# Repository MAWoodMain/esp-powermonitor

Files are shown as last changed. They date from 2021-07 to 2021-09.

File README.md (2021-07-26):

# ESP32-S2 Based Power Meter
This projects sets out to create a standalone power meter with 4 current channels and a voltage channel, this unit should be able to take measurement and publish calibrated values over MQTT to homeassistant and other applications.
This design will focus on having a smaller package and power consumption then similar RPI based solutions like my earlier designs. This design will also integrate a battery backup system to data can be captured during supply drop outs.

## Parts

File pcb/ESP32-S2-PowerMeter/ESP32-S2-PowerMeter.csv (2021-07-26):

Comment | Designator | Footprint | LCSC Part #
1uF Unpolarized capacitor, small symbol | C1,C2,C13 | C_0603_1608Metric | C15849
100nF Unpolarized capacitor, small symbol | C3,C4,C7,C8,C9,C10,C11,C12 | C_0402_1005Metric | C1525
10uF Polarized capacitor, small symbol | C5,C6 | CP_EIA-3216-18_Kemet-A | C7171
FM-B2020RGBA-HG RGB LED, anode/red/green/blue | D1 | FM-B2020RGBA-HG | C108793
ESD9B3.3ST5G ESD protection diode, 3.3Vrwm, SOD-923 | D2,D3,D4,D5 | SMD-DFN1006 | C316039
600R@100MHz Ferrite bead, small symbol | FB1 | L_0402_1005Metric | C96687
MountingHole Mounting Hole without connection | H1 | MountingHole_3.2mm_M3
USB_C_Receptacle_USB2.0 USB 2.0-only Type-C Receptacle connector | J1 | TYPEC-304S-ACP16 | C720630
Battery Generic connector, single row, 01x02, script generated (kicad-library-utils/schlib/autogen/connector/) | J2 | JST_PH_S2B-PH-SM4-TB_1x02-1MP_P2.00mm_Horizontal | C225233
AudioJack3 Audio Jack, 3 Poles (Stereo / TRS) | J3,J4,J5,J6 | PJ-327F | C128989
AC In DC Barrel Jack with an internal switch | J7 | DC-005-5A-2.0-SMT | C319134
Power Path Bypass Solder Jumper, 2-pole, open | JP1 | SolderJumper-2_P1.3mm_Open_RoundedPad1.0x1.5mm
150R Resistor, small symbol | R1 | R_0402_1005Metric | C25082
120R Resistor, small symbol | R2,R3,R4 | R_0402_1005Metric | C25079
5K1 Resistor | R5,R6 | R_0402_1005Metric | C25905
10K Resistor | R7,R9,R10,R11,R13,R14,R15,R16,R17,R18 | R_0402_1005Metric | C25744
1.1K Resistor | R8 | R_0402_1005Metric | C25860
560R Resistor | R12 | R_0402_1005Metric | C25126
22R Resistor, small symbol | R19,R20,R21,R22 | R_0402_1005Metric | C25092
6.8K Resistor | R23 | R_0402_1005Metric | C25917
1K Resistor | R24 | R_0402_1005Metric | C11702
SW_SPDT Switch, single pole double throw | SW1 | MSK12C02-HB | C431541
SW_DIP_x02 2x DIP Switch, Single Pole Single Throw (SPST) switch, small symbol | SW2,SW3 | SW_DIP_SPSTx02_Slide_6.7x6.64mm_W8.61mm_P2.54mm_LowProfile | C129078
10K NTC Temperature dependent resistor | TH1 | R_0402_1005Metric | C77131
VBUS test point | TP1 | TestPoint_THTPad_D2.0mm_Drill1.0mm
VPP test point | TP2 | TestPoint_THTPad_D2.0mm_Drill1.0mm
3V3 test point | TP3 | TestPoint_THTPad_D2.0mm_Drill1.0mm
RX test point | TP4 | TestPoint_Pad_D1.5mm
TX test point | TP5 | TestPoint_Pad_D1.5mm
ESP32-S2-WROVER RF Module, ESP32-D0WDQ6 SoC, Wi-Fi 802.11b/g/n, 32-bit, 2.7-3.6V, onboard antenna, SMD | U1 | ESP32-S2-WROVER
XC6806XXXX11-G | U2 | LGA-10B01
XC6203E332PR | U3 | SOT-89-3 | C19973
CJ432 Shunt Regulator, SOT-23 | U4 | SOT-23 | C8499
LM741 Operational Amplifier, DIP-8/TO-99-8 | U5 | SOP-8_3.9x4.9mm_P1.27mm | C356704

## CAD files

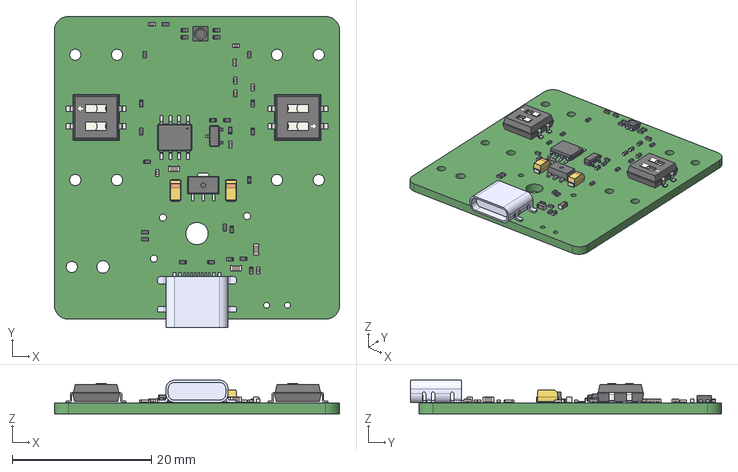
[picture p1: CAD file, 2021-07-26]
pcb/ESP32-S2-PowerMeter/ESP32-S2-PowerMeter.step
41.0 x 44.7 x 4.86 mm

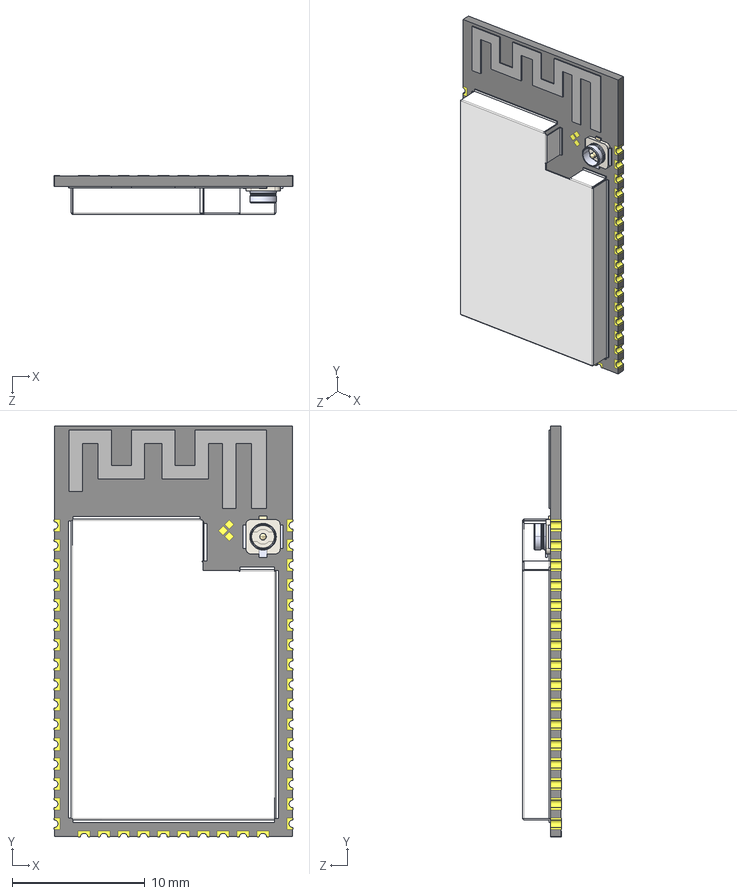
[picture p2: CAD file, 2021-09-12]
pcb/ESP32-S2-PowerMeter/Project Library/3D/ESP32-S2-WROVER.STEP
18.0 x 31.0 x 2.91 mm

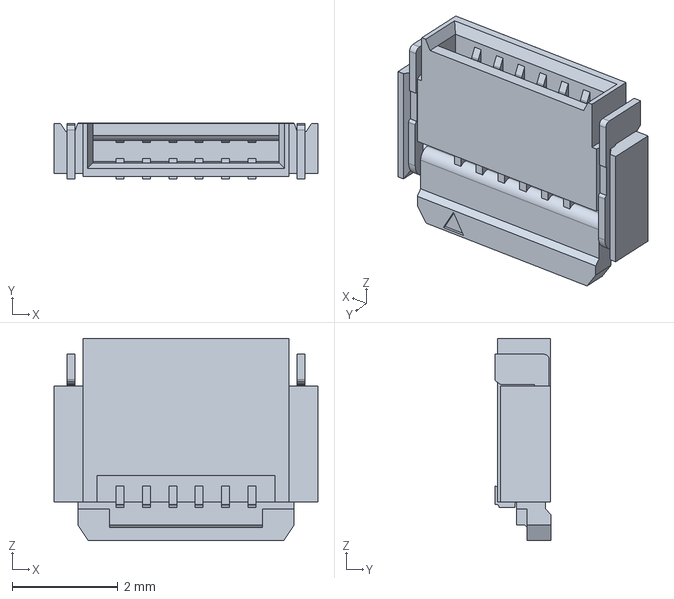
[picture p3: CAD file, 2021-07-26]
pcb/ESP32-S2-PowerMeter/Project Library/3D/c-2328702-6-a-3d.stp
5.00 x 1.06 x 3.83 mm

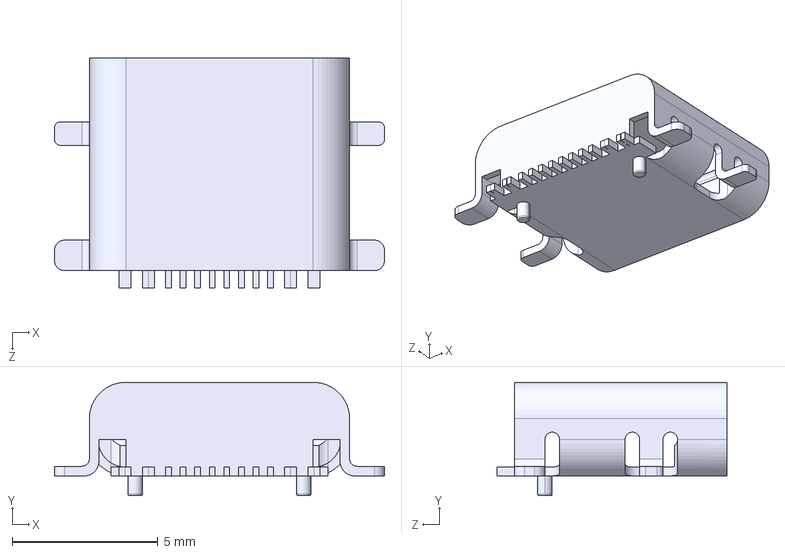
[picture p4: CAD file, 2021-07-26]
pcb/ESP32-S2-PowerMeter/Project Library/3D/XUNPU TYPEC 304S ACP16 C720630.STEP
11.3 x 3.89 x 7.90 mm

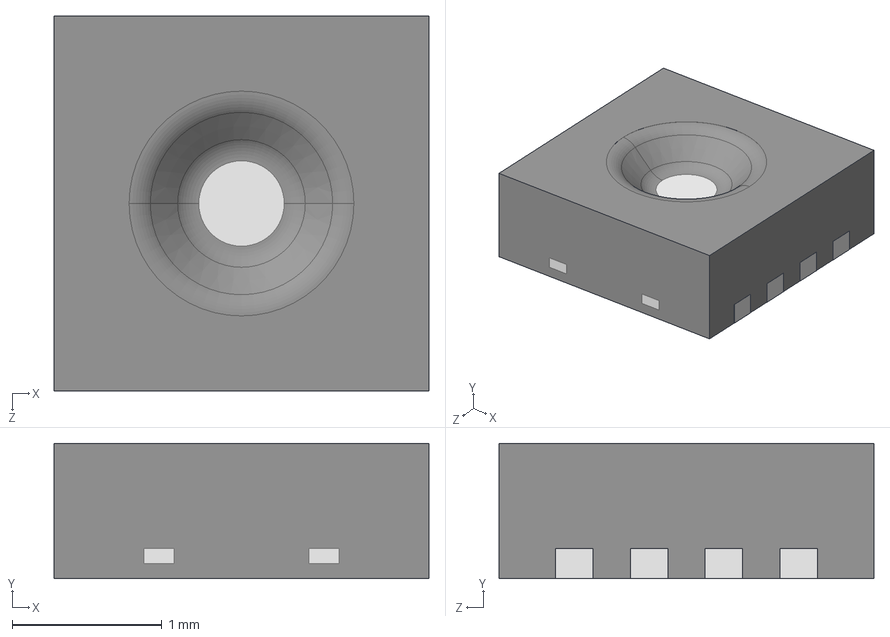
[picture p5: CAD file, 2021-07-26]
pcb/ESP32-S2-PowerMeter/Project Library/3D/Sensirion_Humidity_SHT3x_STEP-file.STEP
2.50 x 0.901 x 2.50 mm

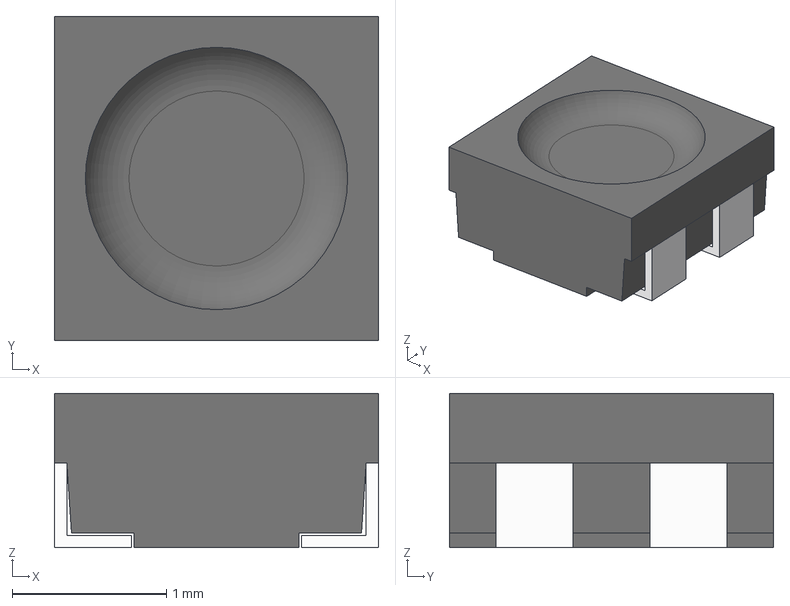
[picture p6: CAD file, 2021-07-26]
pcb/ESP32-S2-PowerMeter/Project Library/3D/FM-B2020RGBA-HG v1.step
2.10 x 2.10 x 1 mm

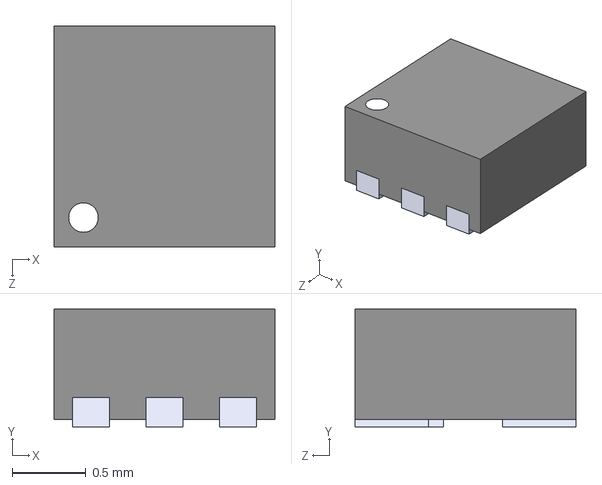
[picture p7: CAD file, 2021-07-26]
pcb/ESP32-S2-PowerMeter/Project Library/3D/TPS610986DSET.step
1.50 x 0.8 x 1.50 mm

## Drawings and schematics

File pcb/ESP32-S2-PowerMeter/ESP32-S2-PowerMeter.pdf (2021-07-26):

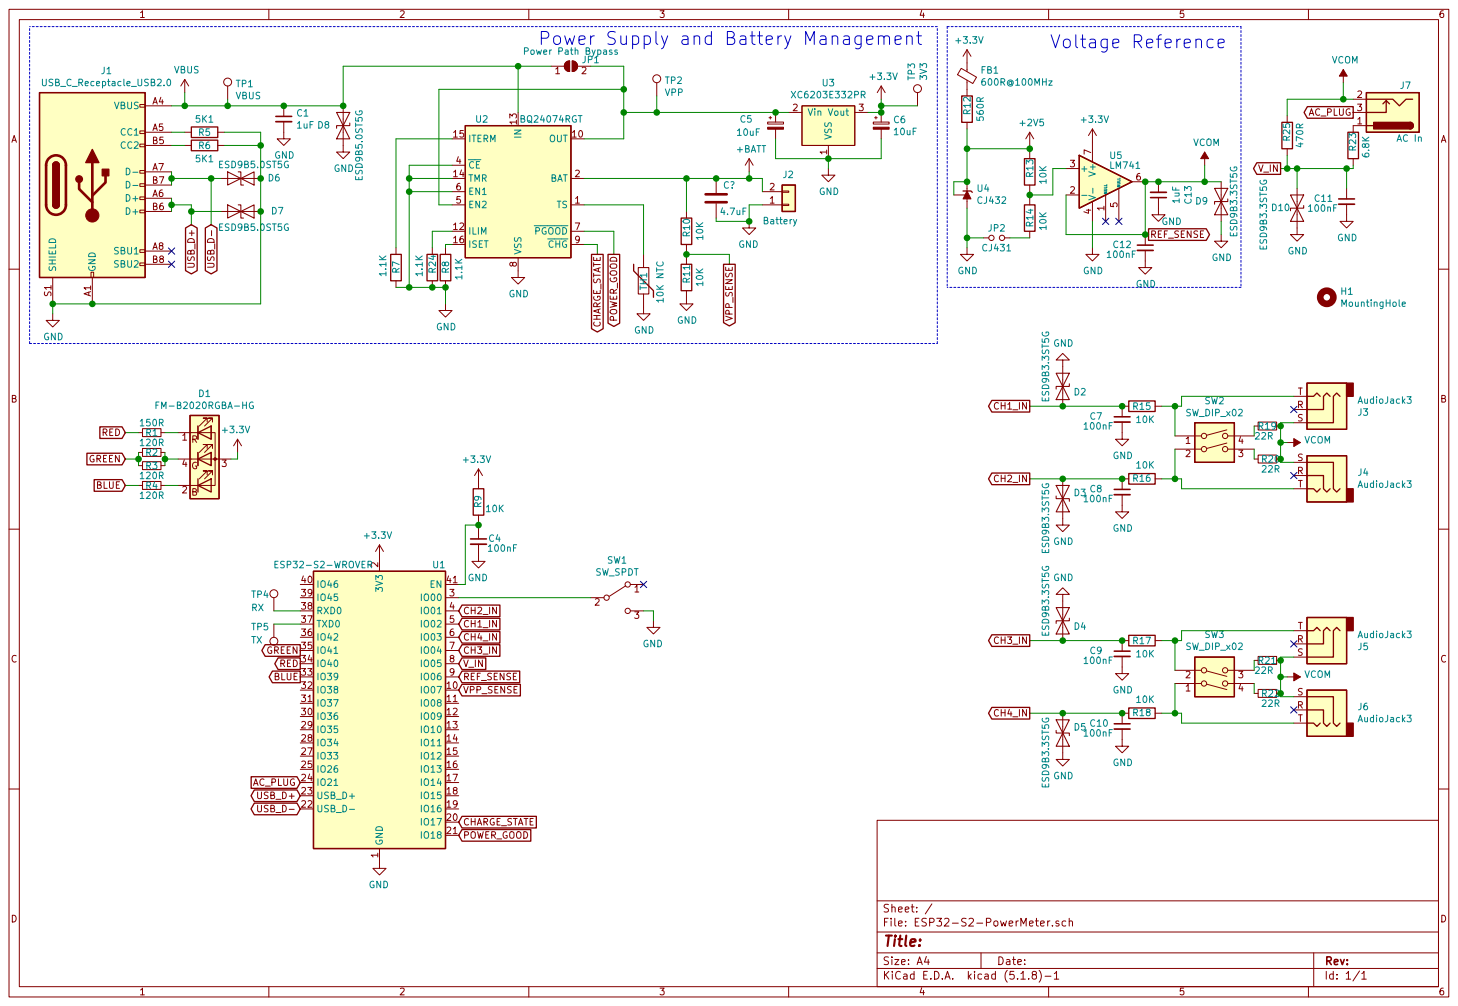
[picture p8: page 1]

JP1 Power Path Bypass +3.3V GND

J7 AC In GND TH1 10K NTC TP2 VPP

Id: 1/1 Title: File: ESP32-S2-PowerMeter.sch Sheet: /

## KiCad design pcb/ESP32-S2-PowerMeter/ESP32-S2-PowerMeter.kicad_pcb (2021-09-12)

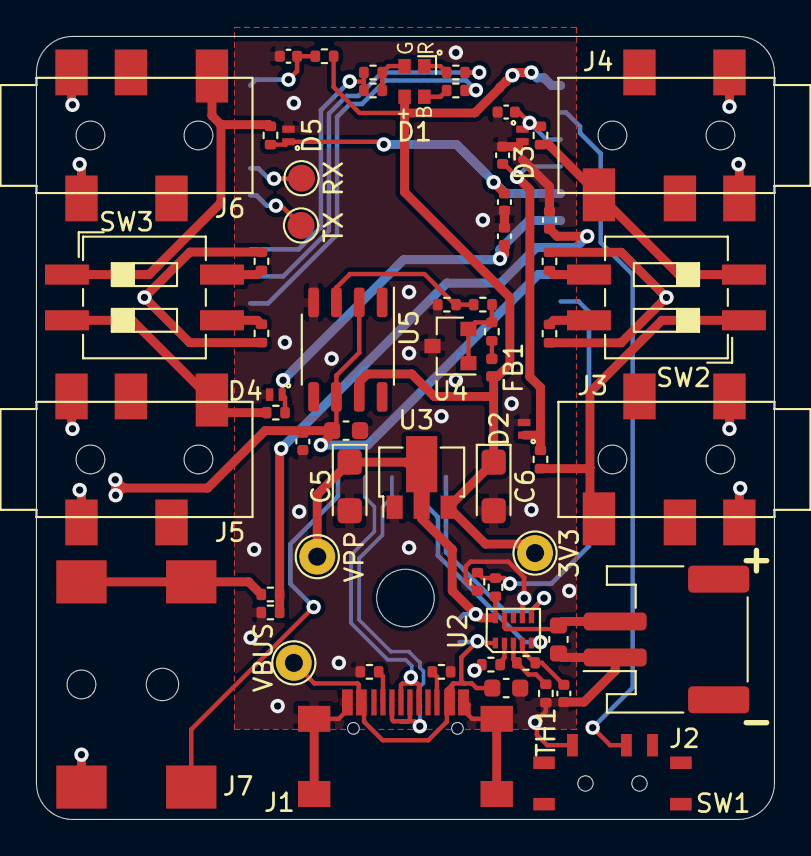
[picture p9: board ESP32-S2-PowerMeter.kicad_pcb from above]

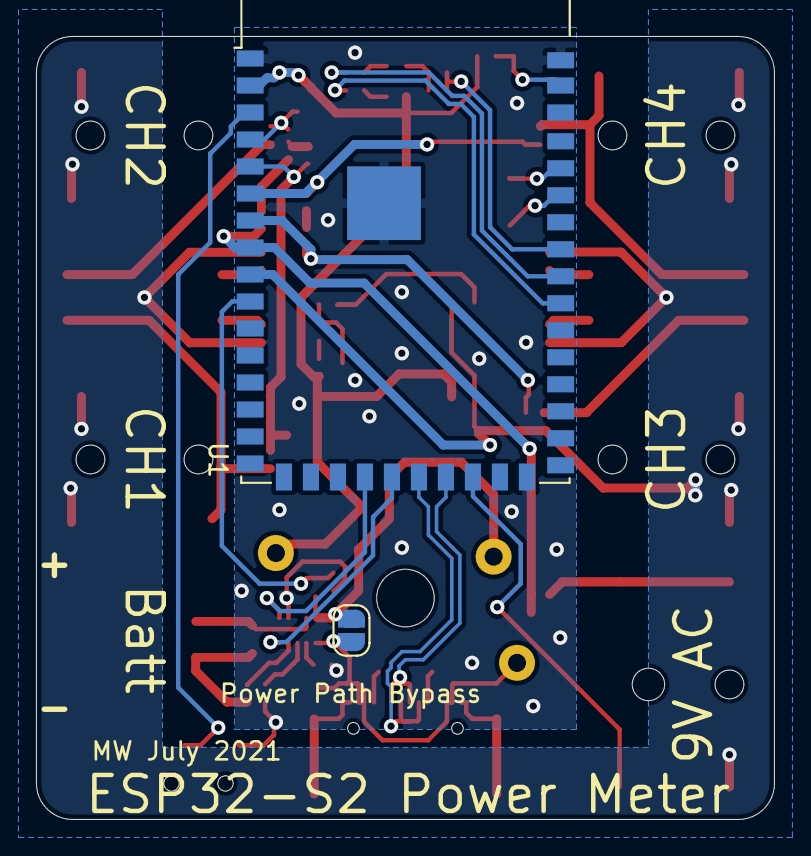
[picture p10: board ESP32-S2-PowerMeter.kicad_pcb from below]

Board: 2 copper layers, 41.0 x 43.5 mm, 66 parts (2 on the bottom side), 44 nets.

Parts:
C1, C2, C13: 1uF; C_0603_1608Metric
C3, C4, C7, C8, C9, C10, C11, C12: 100nF; C_0402_1005Metric
C5, C6: 10uF; CP_EIA-3216-18_Kemet-A
D1: FM-B2020RGBA-HG
D2, D3, D4, D5: ESD9B3.3ST5G; SMD-DFN1006
FB1: 600R@100MHz; L_0402_1005Metric
H1: MountingHole; MountingHole_3.2mm_M3
J1: USB_C_Receptacle_USB2.0; TYPEC-304S-ACP16
J2: Battery; JST_PH_S2B-PH-SM4-TB_1x02-1MP_P2.00mm_Horizontal
J3, J4, J5, J6: AudioJack3; PJ-327F
J7: AC In; DC-005-5A-2.0-SMT
JP1: Power Path Bypass; SolderJumper-2_P1.3mm_Open_RoundedPad1.0x1.5mm
R1: 150; R_0402_1005Metric
R2, R3, R4: 120R; R_0402_1005Metric
R5, R6: 5K1; R_0402_1005Metric
R7, R9, R10, R11, R13, R14, R15, R16, R17, R18: 10K; R_0402_1005Metric
R8: 1.1K; R_0402_1005Metric
R12: 560R; R_0402_1005Metric
R19, R20, R21, R22: Rb; R_0402_1005Metric
R23: 6.8K; R_0402_1005Metric
R24: 1K; R_0402_1005Metric
SW1: SW_SPDT; MSK12C02-HB
SW2, SW3: SW_DIP_x02; SW_DIP_SPSTx02_Slide_6.7x6.64mm_W8.61mm_P2.54mm_LowProfile
TH1: 10K NTC; R_0402_1005Metric
TP1: VBUS; TestPoint_THTPad_D2.0mm_Drill1.0mm
TP2: VPP; TestPoint_THTPad_D2.0mm_Drill1.0mm
TP3: 3V3; TestPoint_THTPad_D2.0mm_Drill1.0mm
TP4: RX; TestPoint_Pad_D1.5mm
TP5: TX; TestPoint_Pad_D1.5mm
U1: ESP32-S2-WROVER
U2: XC6806XXXX11-G; LGA-10B01
U3: XC6203E332PR; SOT-89-3
U4: CJ432; SOT-23
U5: LM741; SOP-8_3.9x4.9mm_P1.27mm

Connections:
+2V5: R12.2, R13.1, U4.1, U4.2
+3V3: C6.1, D1.3, FB1.1, R9.1, TP3.1, U1.2, U3.3, U5.7
+BATT: C2.2, J2.2, U2.9
AC_PLUG: J7.3, U1.24
BLUE: R4.2, U1.33
CH1_IN: C7.1, D2.1, R15.1, U1.5
CH2_IN: C8.1, D3.1, R16.1, U1.4
CH3_IN: C9.1, D4.1, R17.1, U1.7
CH4_IN: C10.1, D5.1, R18.1, U1.6
CHARGE_STATE: U1.20, U2.6
GND: C1.2, C2.1, C3.2, C4.2, C5.2, C6.2, C7.2, C8.2, C9.2, C10.2, C11.2, C12.2, C13.1, D2.2, D3.2, D4.2, D5.2, J1.A1, J1.A12, J1.B1, J1.B12, J1.S1, J2.1, R5.1, R6.1, R8.2, R11.2, R14.2, R24.2, SW1.3, TH1.2, U1.1, U1.26, U1.42, U1.43, U2.7, U3.1, U4.3, U5.4
GREEN: R2.2, R3.2, U1.35
unnamed: C3.1, R7.1, U2.4
unnamed: C4.1, R9.2, U1.41
unnamed: C5.1, JP1.2, R10.1, TP2.1, U2.10, U3.2
unnamed: D1.1, R1.1
unnamed: D1.2, R4.1
unnamed: D1.4, R2.1, R3.1
unnamed: FB1.2, R12.1
unnamed: J1.A5, R5.2
unnamed: J1.B5, R6.2
unnamed: J3.T, R15.2, SW2.1
unnamed: J4.T, R16.2, SW2.2
unnamed: J5.T, R17.2, SW3.2
unnamed: J6.T, R18.2, SW3.1
unnamed: J7.1, R23.1
unnamed: R7.2, TH1.1, U2.3
unnamed: R8.1, U2.2
unnamed: R13.2, R14.1, U5.3
unnamed: R19.1, SW2.4
unnamed: R20.2, SW2.3
unnamed: R21.1, SW3.3
unnamed: R22.2, SW3.4
unnamed: SW1.2, U1.3
unnamed: TP4.1, U1.38
unnamed: TP5.1, U1.37
POWER_GOOD: U1.21, U2.5
RED: R1.2, U1.34
REF_SENSE: C12.1, C13.2, J3.S, J4.S, J5.S, J6.S, J7.2, R19.2, R20.1, R21.2, R22.1, U1.9, U5.2, U5.6
USB_D+: J1.A6, J1.B6, U1.23
USB_D-: J1.A7, J1.B7, U1.22
VBUS: C1.1, J1.A4, J1.A9, J1.B4, J1.B9, JP1.1, TP1.1, U2.1
VPP_SENSE: R10.2, R11.1, U1.10
V_IN: C11.1, R23.2, R24.1, U1.8

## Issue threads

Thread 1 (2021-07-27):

AC input not functioning as expected

MAWoodMain, 2021-07-27:
On initial bring up the AC voltage input was clipping on the internal clamping diodes, the scaling is incorrect.

Circuit tweaked and resigned in circuitjs, live simulation can be found here:
https://tinyurl.com/yjgqgnyt

In terms of rework to make the current board servicable,

1. Remove R24
2. Fit a THT 470Ohm resistor from the non gnd side of R24's footprint to pin 2 of U5

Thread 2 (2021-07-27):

Voltage reference voltage is incorrect

MAWoodMain, 2021-07-27:
By mistake the board was designed and assembled with a CJ432 ranther then the CJ431 originally intended, to resolve this the lower side of the divider can be removed (R14). On future hardware issues this will be configured using a NO jumper

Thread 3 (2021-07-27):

ESP spontaniously broken on USB insertion

MAWoodMain, 2021-07-27:
After many cycles of usb insertion and removal the ESP randomly died, no particular cause has been accreditited to this but ESD is suspected, to resolve this on first issues PCBs a USB6B1 IC can be reworked onto the USB and 5V lines. If this occurs again, other possible causes will be investigated

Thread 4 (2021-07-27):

Optional battery interface

MAWoodMain, 2021-07-27:
The original intended IC the XC6806 has a tricking footprint that I have foolishly placed passive components too close to making it extremely difficult to rework into place. The design will be adjusted in future issues to use a part which can be JLCPCB assembled to remove the need to manually rework the IC on.

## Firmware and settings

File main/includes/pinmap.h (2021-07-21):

//
// Created by MattWood on 15/07/2021.
//

#ifndef PINMAP_H
#define PINMAP_H

#include "driver/gpio.h"
#include "driver/adc.h"
/**************************** LIB INCLUDES ******************************/
/**************************** USER INCLUDES *****************************/
/******************************* DEFINES ********************************/

#if CONFIG_PM_REAL_HARDWARE

/* LED */
#define PINMAP_LED_RED      GPIO_NUM_40
#define PINMAP_LED_GREEN    GPIO_NUM_41
#define PINMAP_LED_BLUE     GPIO_NUM_39

#define PINMAP_LED_INVERTED true

/* Battery management */
#define PINMAP_BAT_PG       GPIO_NUM_18
#define PINMAP_BAT_CSO      GPIO_NUM_17
#define PINMAP_BAT_SEN_ADC  ADC1_CHANNEL_6

/* Power monitor */
#define PINMAP_PM_REF_ADC   ADC1_CHANNEL_5

#define PINMAP_PM_V_SEN_ADC ADC1_CHANNEL_4
#define PINMAP_PM_V_PLUG    GPIO_NUM_21

#define PINMAP_PM_CH1_ADC   ADC1_CHANNEL_1
#define PINMAP_PM_CH2_ADC   ADC1_CHANNEL_0
#define PINMAP_PM_CH3_ADC   ADC1_CHANNEL_3
#define PINMAP_PM_CH4_ADC   ADC1_CHANNEL_2

/* Diagnostics */
#define PINMAP_ISR_TIMING   GPIO_NUM_6
#define PINMAP_TASK_TIMING  GPIO_NUM_7
#define PINMAP_TRANSMIT_TIMING  GPIO_NUM_8

#else

/* LED */
#define PINMAP_LED_RED      GPIO_NUM_15
#define PINMAP_LED_GREEN    GPIO_NUM_14
#define PINMAP_LED_BLUE     GPIO_NUM_26

#define PINMAP_LED_INVERTED false

/* Battery management */
#define PINMAP_BAT_PG       GPIO_NUM_18
#define PINMAP_BAT_CSO      GPIO_NUM_17
#define PINMAP_BAT_SEN_ADC  ADC1_CHANNEL_6

/* Power monitor */
#define PINMAP_PM_REF_ADC   ADC1_CHANNEL_5

#define PINMAP_PM_V_SEN_ADC ADC1_CHANNEL_1
#define PINMAP_PM_V_PLUG    GPIO_NUM_21

#define PINMAP_PM_CH1_ADC   ADC1_CHANNEL_1
#define PINMAP_PM_CH2_ADC   ADC1_CHANNEL_1
#define PINMAP_PM_CH3_ADC   ADC1_CHANNEL_1
#define PINMAP_PM_CH4_ADC   ADC1_CHANNEL_1

/* Diagnostics */
#define PINMAP_ISR_TIMING   GPIO_NUM_6
#define PINMAP_TASK_TIMING  GPIO_NUM_7
#define PINMAP_TRANSMIT_TIMING  GPIO_NUM_8

#endif

/******************************** ENUMS *********************************/
/****************************** TYPEDEFS ********************************/
/***************************** STRUCTURES *******************************/
/************************** FUNCTION PROTOTYPES *************************/
/******************************* GLOBALS ********************************/

#endif /* PINMAP_H */

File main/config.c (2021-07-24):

//
// Created by MattWood on 21/07/2021.
//

/**************************** LIB INCLUDES ******************************/
/**************************** USER INCLUDES *****************************/
#include "config.h"
#include "esp_spiffs.h"
#include "jsmn.h"
/******************************* DEFINES ********************************/
#define CONFIG_SAVE_FILE_BUFFER_LENGTH 512
/***************************** STRUCTURES *******************************/
/************************** FUNCTION PROTOTYPES *************************/
bool config_parseConfigFile();
void config_extractStringField(config_string_field_e field, jsmntok_t *t, char *json);
void config_extractFloatField(config_float_field_e field, jsmntok_t *t, char *json);
/******************************* CONSTANTS ******************************/
static const char *TAG = "CONFIG";
static const char* config_configFilename = "config.json";
static const char* config_jsonStringFieldNames[CONFIG_STRING_FIELD_MAX] =
        {
                [CONFIG_STRING_FIELD_WIFI_SSID]         = "wifi_ssid",
                [CONFIG_STRING_FIELD_WIFI_PASSWORD]     = "wifi_password",
                [CONFIG_STRING_FIELD_MQTT_URI]          = "mqtt_uri",
                [CONFIG_STRING_FIELD_MQTT_USERNAME]     = "mqtt_username",
                [CONFIG_STRING_FIELD_MQTT_PASSWORD]     = "mqtt_password"
        };
static const char* config_jsonFloatFieldNames[CONFIG_FLOAT_FIELD_MAX] =
        {
                [CONFIG_FLOAT_FIELD_V_CAL]      = "cal_v_cal",
                [CONFIG_FLOAT_FIELD_I1_CAL]     = "cal_i1_cal",
                [CONFIG_FLOAT_FIELD_I2_CAL]     = "cal_i2_cal",
                [CONFIG_FLOAT_FIELD_I3_CAL]     = "cal_i3_cal",
                [CONFIG_FLOAT_FIELD_I4_CAL]     = "cal_i4_cal"
        };
/******************************* VARIABLES ******************************/
char config_configSaveFileBuffer[CONFIG_SAVE_FILE_BUFFER_LENGTH];

static char* config_stringFieldValues[CONFIG_STRING_FIELD_MAX] =
        {
                [CONFIG_STRING_FIELD_WIFI_SSID]         = "default_ssid",
                [CONFIG_STRING_FIELD_WIFI_PASSWORD]     = "default_password",
                [CONFIG_STRING_FIELD_MQTT_URI]          = "default_uri",
                [CONFIG_STRING_FIELD_MQTT_USERNAME]     = "default_username",
                [CONFIG_STRING_FIELD_MQTT_PASSWORD]     = "default_password"
        };
static float config_floatFieldValues[CONFIG_FLOAT_FIELD_MAX] =
        {
                [CONFIG_FLOAT_FIELD_V_CAL]      = 1.0f,
                [CONFIG_FLOAT_FIELD_I1_CAL]     = 1.0f,
                [CONFIG_FLOAT_FIELD_I2_CAL]     = 1.0f,
                [CONFIG_FLOAT_FIELD_I3_CAL]     = 1.0f,
                [CONFIG_FLOAT_FIELD_I4_CAL]     = 1.0f
        };
/*************************** PUBLIC FUNCTIONS ***************************/
bool config_init()
{
    bool retVal = true;

    ESP_LOGI(TAG, "Initializing SPIFFS");

    esp_vfs_spiffs_conf_t conf = {
            .base_path = "/spiffs",
            .partition_label = NULL,
            .max_files = 5,
            .format_if_mount_failed = false
    };

    // Use settings defined above to initialize and mount SPIFFS filesystem.
    // Note: esp_vfs_spiffs_register is an all-in-one convenience function.
    esp_err_t ret = esp_vfs_spiffs_register(&conf);

    if (ret != ESP_OK) {
        if (ret == ESP_FAIL) {
            ESP_LOGE(TAG, "Failed to mount or format filesystem");
        } else if (ret == ESP_ERR_NOT_FOUND) {
            ESP_LOGE(TAG, "Failed to find SPIFFS partition");
        } else {
            ESP_LOGE(TAG, "Failed to initialize SPIFFS (%s)", esp_err_to_name(ret));
        }
        retVal = false;
    }
    else
    {
        size_t total = 0, used = 0;
        ret = esp_spiffs_info(NULL, &total, &used);
        if (ret != ESP_OK) {
            ESP_LOGE(TAG, "Failed to get SPIFFS partition information (%s)", esp_err_to_name(ret));
        } else {
            ESP_LOGI(TAG, "Partition size: total: %d, used: %d", total, used);
        }

        if(false == config_parseConfigFile())
        {
            if(false == config_save())
            {
                retVal = false;
            }
        }
    }

    return retVal;
}

char* config_getStringField(config_string_field_e field)
{
    char *retVal = NULL;

    if(field < CONFIG_STRING_FIELD_MAX)
    {
        retVal = config_stringFieldValues[field];
    }

    if(retVal == NULL)
    {
        retVal = "";
    }

    return retVal;
}

void config_setStringField(config_string_field_e field, char* newValue)
{
    uint32_t newStringLength = strlen(newValue);

    if(field < CONFIG_STRING_FIELD_MAX)
    {
        free(config_stringFieldValues[field]);
        config_stringFieldValues[field] = calloc(newStringLength + 1, sizeof(char));
        strcpy(config_stringFieldValues[field], newValue);
    }
}

float config_getFloatField(config_float_field_e field)
{
    if(field < CONFIG_FLOAT_FIELD_MAX)
    {
        return config_floatFieldValues[field];
    }
    return 0.0f;
}

void config_setFloatField(config_float_field_e field, float newValue)
{
    if(field < CONFIG_FLOAT_FIELD_MAX)
    {
        config_floatFieldValues[field] = newValue;
    }
}

bool config_save()
{
    bool retVal = false;
    char fileName[64];
    FILE* f;
    uint32_t length = 0;
    memset(config_configSaveFileBuffer, 0, CONFIG_SAVE_FILE_BUFFER_LENGTH);

    sprintf(config_configSaveFileBuffer, "{");
    for(uint32_t idx = 0; idx < CONFIG_STRING_FIELD_MAX; idx++)
    {
        if(idx != 0)
        {
            sprintf(config_configSaveFileBuffer + strlen(config_configSaveFileBuffer), ",");
        }
        sprintf(config_configSaveFileBuffer + strlen(config_configSaveFileBuffer), "\"%s\":\"%s\"", config_jsonStringFieldNames[idx], config_stringFieldValues[idx]);
    }

    for(uint32_t idx = 0; idx < CONFIG_FLOAT_FIELD_MAX; idx++)
    {
        sprintf(config_configSaveFileBuffer + strlen(config_configSaveFileBuffer), ",");
        sprintf(config_configSaveFileBuffer + strlen(config_configSaveFileBuffer), "\"%s\":%f", config_jsonFloatFieldNames[idx], config_floatFieldValues[idx]);
    }
    sprintf(config_configSaveFileBuffer + strlen(config_configSaveFileBuffer), "}");
    ESP_LOGI(TAG, "new config: %s", config_configSaveFileBuffer);

    length = strlen(config_configSaveFileBuffer);

    memset(fileName, 0, sizeof(fileName));
    strcpy(fileName, "/spiffs/");
    strcat(fileName, config_configFilename);

    f = fopen(fileName, "w");
    retVal = length == fwrite(config_configSaveFileBuffer, 1, length, f);

    fclose(f);
    return retVal;
}
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

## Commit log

2021-07-15 Initial commit, hello world example with basic LED driver and pinmap added
2021-07-17 Implemented a sampling system to sample the channels at 1khz and dispatch blocks of 1000 samples to a task for processing
2021-07-18 Added current min and max, also added frequency measurement
2021-07-21 Added measurement condition and performed tweaks for real hardware, also increased app size to 1.5M with otafu but no factory image
    [partitions_two_ota_nofact.csv]
2021-07-21 Organised wifi and mqtt into specific files and added a webserver for configuration (currently just hosting a demo static file)
2021-07-21 Added file system and setup json file to be loaded which contains the wifi and mqtt details
    [partitions_two_ota_nofact.csv]
2021-07-24 Added battery system and started developing web interface, still WIP
2021-07-24 Added calibration to web UI
2021-07-24 Added VA and P, also made the device write a default config file in
2021-07-24 Since the charger IC is misbehaving simplified batter reporting to charging/discharging
2021-07-24 Fixed bug where I cal did not work and also recals did not consider existing cal
    [power_monitor.c]
2021-07-24 Added cal reset button
2021-07-26 Added PCB to git
    [ESP32-S2-PowerMeter-B_Cu.gbr, ESP32-S2-PowerMeter-B_Mask.gbr, ESP32-S2-PowerMeter-B_Paste.gbr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]
2021-07-26 Updated schematic - Added ESD diodes to USB and V sense - Fixed V sense input to be reference centered - Added jumper to choose between CJ431 and CJ432 - Replaced XC6806 with JLC assemble-able BQ2407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
    [ESP32-S2-PowerMeter.sch]
2021-09-12 Added battery not fitted state
    [battery.c]
2021-09-12 Added module step file and re-exported assembly step file
    [ESP32-S2-PowerMeter.kicad_pcb, ESP32-S2-WROVER.STEP]
